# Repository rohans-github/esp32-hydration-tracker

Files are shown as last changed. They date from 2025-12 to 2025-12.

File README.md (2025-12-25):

# Hydration Tracker Using ESP32 Microcontroller
Created by Rohan

## Table of Contents
* [Report](#report)
* [Hardware Setup](#hardware-setup)
* [Code](#code)
* [Media](#media)
* [Citations](#citations)

## Report

### Quick Overview
The Hydration Tracker is a smart water bottle scale that helps users maintain proper hydration throughout the day. The device monitors water consumption in real-time, provides visual feedback on hydration status through the onboard LED and the website it hosts, and logs historical data for tracking progress over time.

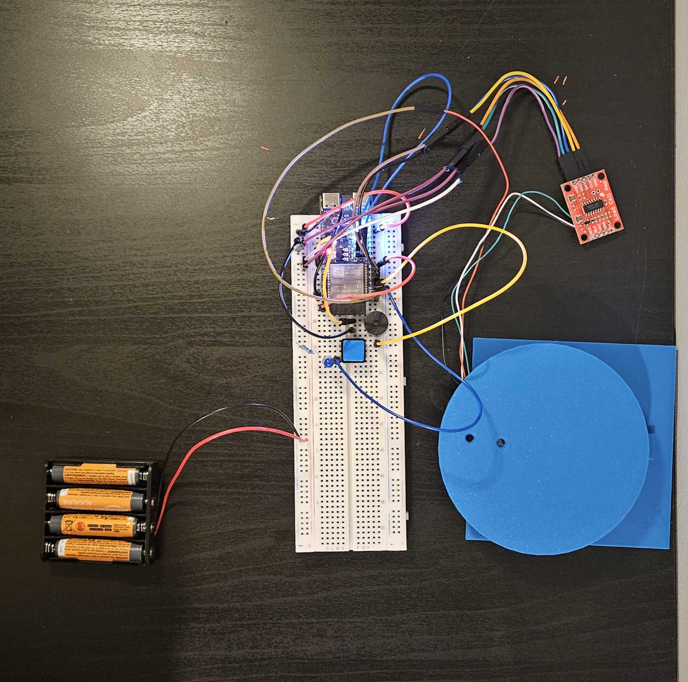
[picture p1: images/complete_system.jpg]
Complete System


### Component Overview
For the Hydration Tracker hardware, the following components are required:
* ESP32-C6-DevKitC-1 Microcontroller
  * The ESP32C6 contains the logic for the system and interacts with the other peripherals such as the buzzer to provide meaningful functionality.
  * Additionally, the onboard LED of the ESP32C6 acts as a visual indicator, showing white for when the system is waiting for user input for a session, red when the user is substantially behind their ideal hydration level during the session, yellow when the user is slightly behind their ideal hydration level during the session, green when the user is ahead of their ideal hydration level during the session, and purple when the user is at or surpasses their hydration goal for the session.
* HX711 Load Cell Amplifier
  * The load cell amplifier amplifies the tiny voltage offsets from the load cell into a more useable range of voltage that correlates to weight readings.
* Load Cell (5kg capacity)
  * The load cell measures strain along itself and outputs it as a change in voltage. The change in strain is measurable as a change in weight.
* Blue LED
  * The blue LED provides visual feedback to when the system is hosting the webpage. When the LED is on, the user is able to access the webpage.
* Button
  * The button tells the system to turn on WiFi capabilities so that the user can connect to it and view the webpage that the system hosts.
* Buzzer
  * The buzzer audibly notifies the user that they need to drink water to stay on track with their hydration goal for the session.
* Battery Pack
  * The battery pack is necessary to power on the system in a portable manner.
* Breadboard
  * The breadboard is necessary to easily connect all components together.
    
 ### Challenges Faced
 - Task running out of stack storage, which was solved by allocating more of the stack to the task
 - Getting NVS to work and store the session data
 - Separating the project into independent modules
 - External RGB LED had many flaws, had to switch to onboard LED
 - Had problems implementing sleep mode since the system would not register scale readings in sleep, making the system unresponsive and frustrating. To somewhat still save power, we implemented the web server button since WiFi was the peripheral that took up the most power.

### Similarities and Differences to Other Real-World Embedded Systems
The system is similar to other embedded systems in several areas, such as interactivity, responsive, and power. Some real-world embedded systems are interactive and have buttons, such as a car's AC system, that allow the user to use the system. Additionally, real-world embedded systems are responsive, meaning that clicking a button doesn't have a noticeable delay. The Hydration Monitor promotes user interactivity by hosting a web server where users can view and reset their hydration data. The web server button is connected to an interrupt, making it responsive as well. Real-world embedded systems should also be conservative in power as most of these systems run on an external battery. In this project, the system is able to disable web server and WiFi capabilities after it senses no clients for a set time, thus saving power. A major difference between this system and other real-world embedded systems is size. Most embedded systems implement a custom PCB to minimize the size of their system. This project on the other hand uses a breadboard and long wires that greatly increases its size, making it inconvenient to carry around and use.

### Improvements
Given more time and resources, some improvements could be
- Making UI/UX on website better
- Constructing scale with better materials and adding more structural support to stabilize scale when heavy objects are placed on it
- Implementing better logic to reliably detect hydration intake since some hydration intakes did not go through
- Soldering and reducing wire usage
- Creating custom PCB instead of ESP32 board

## Hardware Setup

### Wiring

| ESP32-C6 Pin | HX711 | Blue LED| Speaker | Push Button | Power |
| :---: | :---: | :-----: | :-----: | :---: | :---: |
| 5V | VCC | | | | + | 
| GND | GND | Cathode | - | GND | - |
| GPIO 4 | |  Anode  | | | |
| GPIO 5 | | | | Signal | |
| GPIO 6 | DAT | | | | |
| GPIO 7 | CLK | | | | |
| GPIO 21 | | | + | | |

**Load Cell Wiring:**
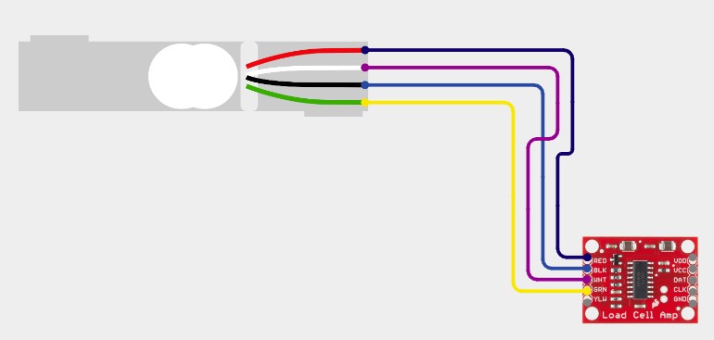
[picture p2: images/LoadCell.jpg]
LoadCell
### 

- E+ → RED
- E- → BLK
- A- → WHT
- A+ → GRN

**Circuit Diagram:**
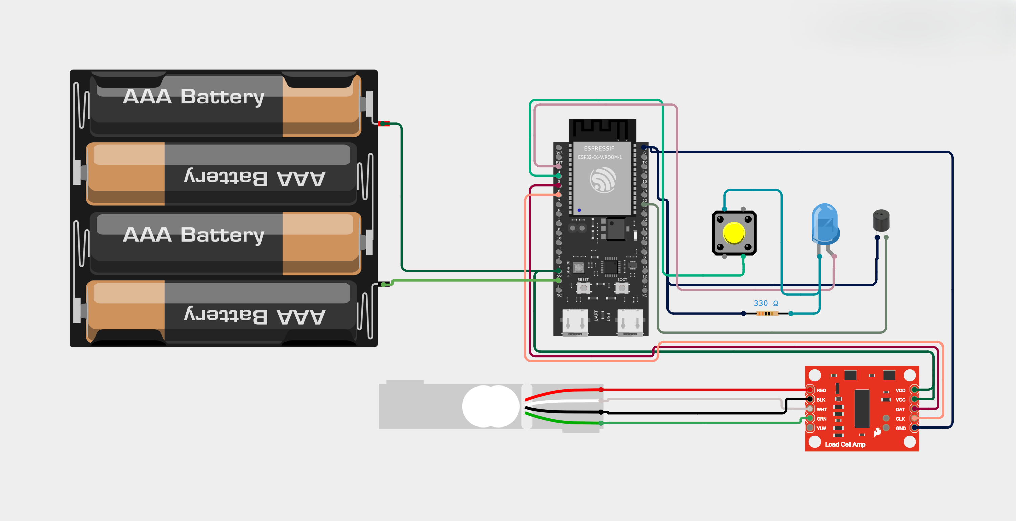
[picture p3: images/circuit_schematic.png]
Circuit Diagram
### 

### Assembly Notes

The load cell should be mounted in a stable configuration to accurately measure the weight of the water bottle. We recommend:
1. Securing the load cell to a flat, rigid base
2. Creating a platform on top of the load cell for the water bottle to rest on
3. Ensuring the load cell is calibrated before first use (calibration value in `config.h`)

The blue LED serves as a web server status indicator:
- **Solid Blue**: Web server enabled
- **Off**: Web server disabled

The onboard LED provides hydration status feedback:
- **Green**: On track with hydration goals
- **Yellow**: Falling behind, should drink soon  
- **Red**: Critical, need to drink immediately

## Code

### Module Architecture

The codebase is organized into modular components, each handling a specific aspect of the system:

#### **config.h**
Central configuration file containing:
- Pin definitions for all hardware components
- Calibration values for the load cell
- LED state definitions for different hydration levels
- Storage configuration for historical data

#### **scale.cpp / scale.h**
Handles the HX711 load cell interface:
- Initializes the HX711 with calibration values
- Reads weight measurements with stability checking
- Calculates delta (change in weight) to detect water consumption
- Implements filtering to reduce noise

#### **hydration.cpp / hydration.h**
Manages hydration tracking logic:
- Tracks total water consumed vs. session goal
- Calculates ideal consumption rate over time
- Determines hydration state (HYDRATED, NEEDS_WATER, CRITICAL)
- Updates status based on consumption pattern
- Provides reset functionality for new session periods

#### **status_led.cpp / status_led.h**
Controls the onboard LED feedback:
- Initializes the ESP32-C6 onboard LED
- Maps hydration states to LED patterns:
  - **Green**: On track with hydration
  - **Yellow**: Falling behind, should drink soon
  - **Red**: Critical, need to drink immediately
  - **Purple**: Met/exceeded session goal
- Provides visual status at a glance

#### **speaker.cpp / speaker.h**
Manages audio alerts:
- Generates tone alerts using PWM
- Plays periodic reminders when hydration is critical
- Implements alert timing to avoid annoyance
- Can be silenced when hydration improves

#### **storage.cpp / storage.h**
Handles non-volatile memory operations:
- Stores up to 7 sessions using NVS (Non-Volatile Storage)
- Each session saves daily consumption data with session lengths
- Provides data retrieval for web interface

#### **web.cpp / web.h**
Implements WiFi access point and web server:
- Creates a WiFi hotspot (SSID: "Hydration Tracker")
- Serves HTML page with real-time hydration data
- Provides AJAX endpoints for live updates
- Displays historical consumption in table format
- Allows users to reset tracking data
- Can be toggled on/off via push button

#### **4180.ino**
Main program file that:
- Initializes all hardware modules
- Creates FreeRTOS tasks for concurrent operation:
  - `taskReadScale`: Monitors scale for weight changes (every 100ms)
  - `taskUpdateStatusLED`: Updates onboard LED based on hydration state (every 2s)
  - `taskAlertUser`: Triggers speaker alerts when needed (every 1s)
  - `taskHTMLPage`: Handles web server requests (every 10ms)
  - `taskWiFiControl`: Manages WiFi button and blue LED status
- Manages end-of-day data logging and resets

## Media

### System Overview
Complete System
*Fully assembled hydration tracker with ESP32-C6, load cell, blue WiFi LED, push button, and speaker*

### Hardware Components
Hardware Setup
*Wiring diagram showing connections between ESP32-C6, HX711, and peripherals*

### LED Status Indicators
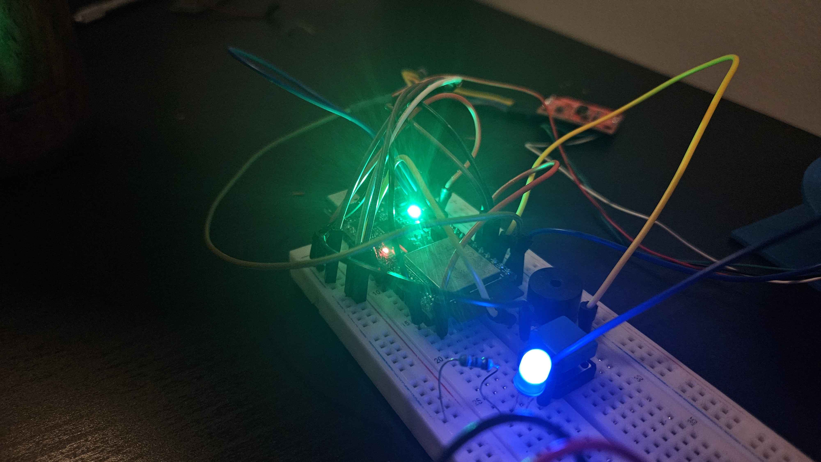
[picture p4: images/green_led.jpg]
Onboard LED - Hydrated

*Green onboard LED indicating good hydration status*

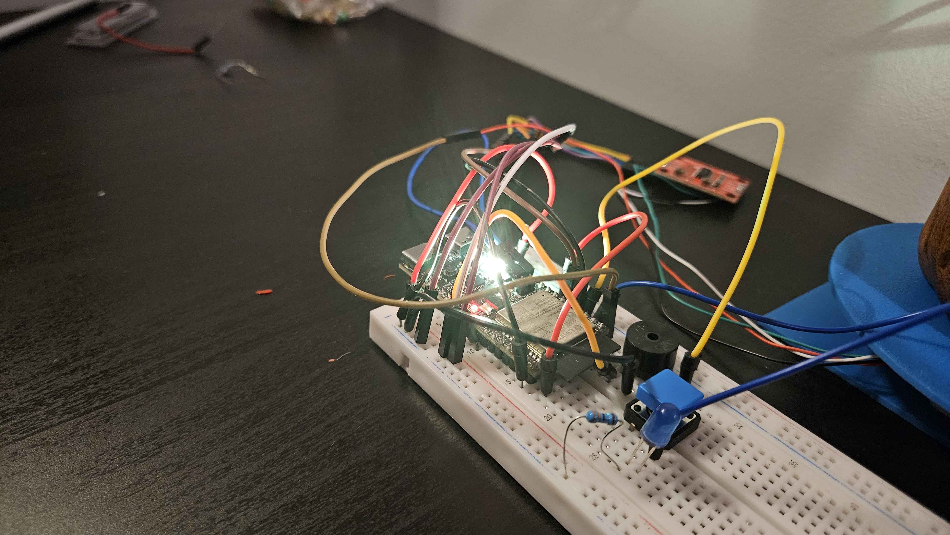
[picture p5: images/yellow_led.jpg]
Onboard LED - Needs Water

*Yellow onboard LED indicating user should drink soon*

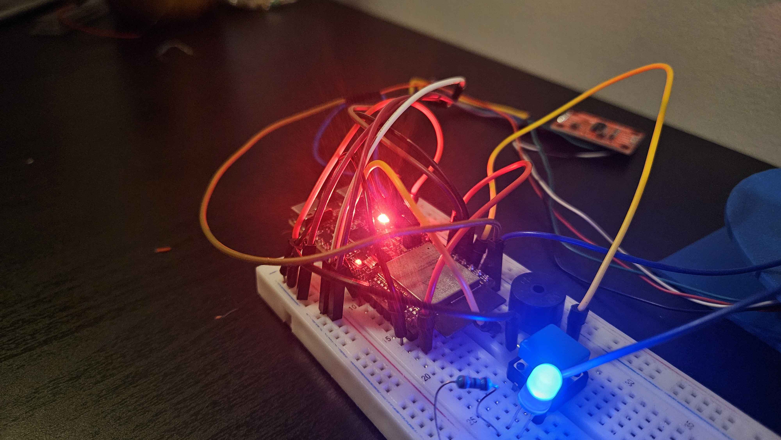
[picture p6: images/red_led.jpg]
Onboard LED - Critical

*Red onboard LED indicating critical hydration status*

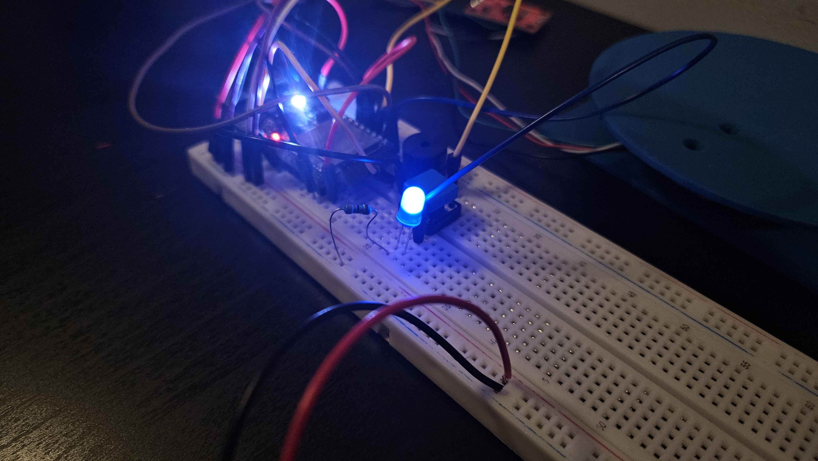
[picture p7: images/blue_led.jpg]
Blue WiFi LED

*Blue LED indicating WiFi is active and web interface is accessible*

### Web Interface
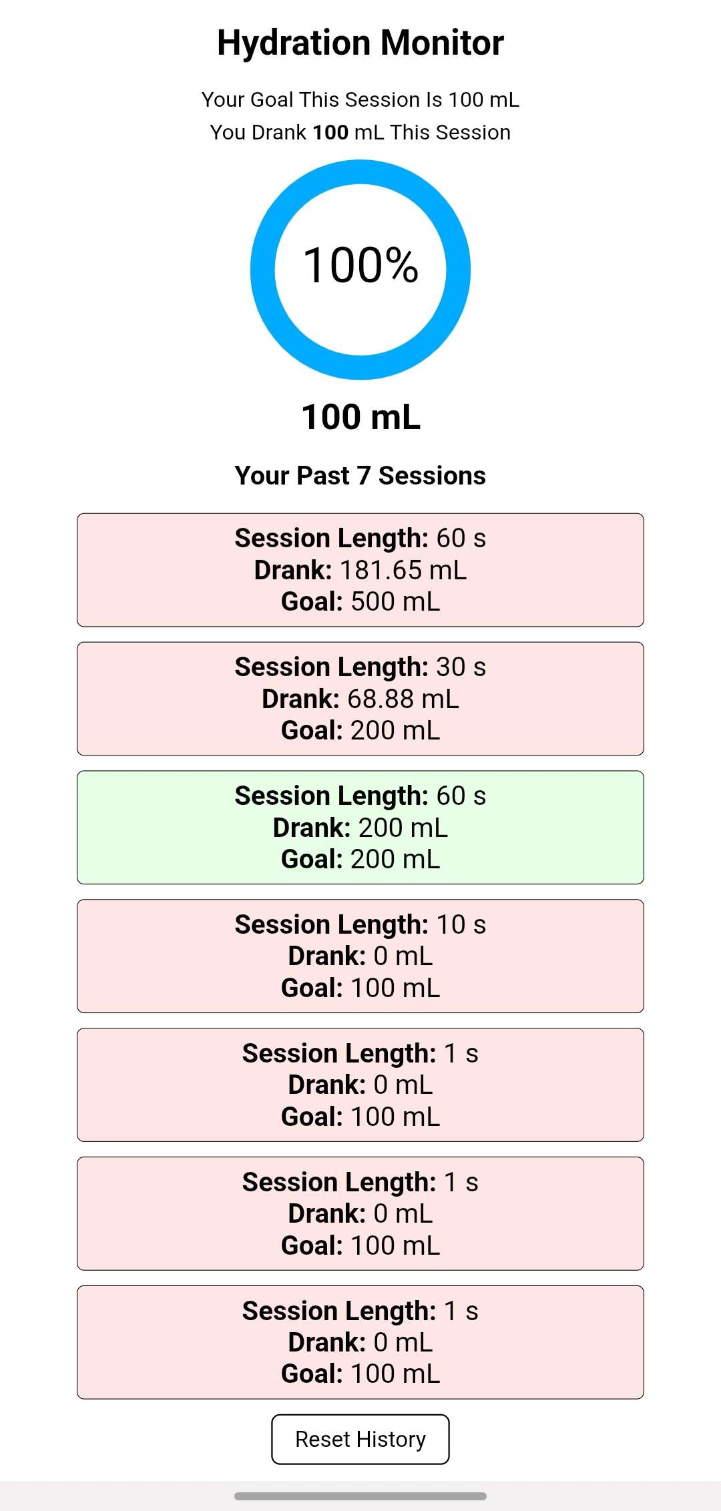
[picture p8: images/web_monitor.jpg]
Web Dashboard

*Web interface showing current hydration level and 7-day history*

### Device in Use
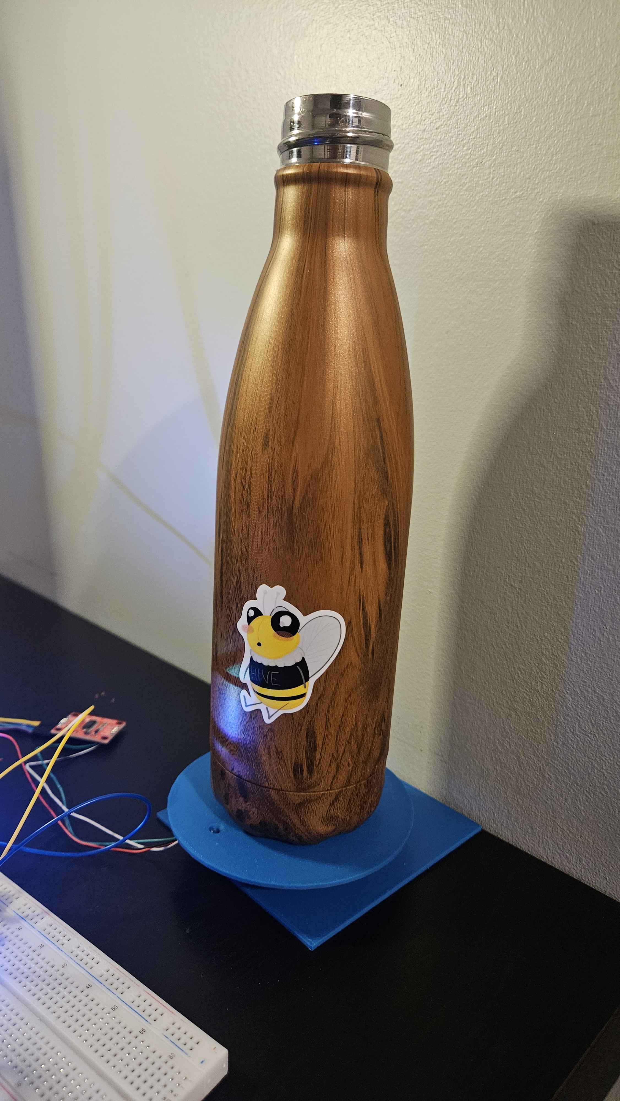
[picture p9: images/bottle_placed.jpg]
Water Bottle on Scale

*Water bottle positioned on the load cell platform*

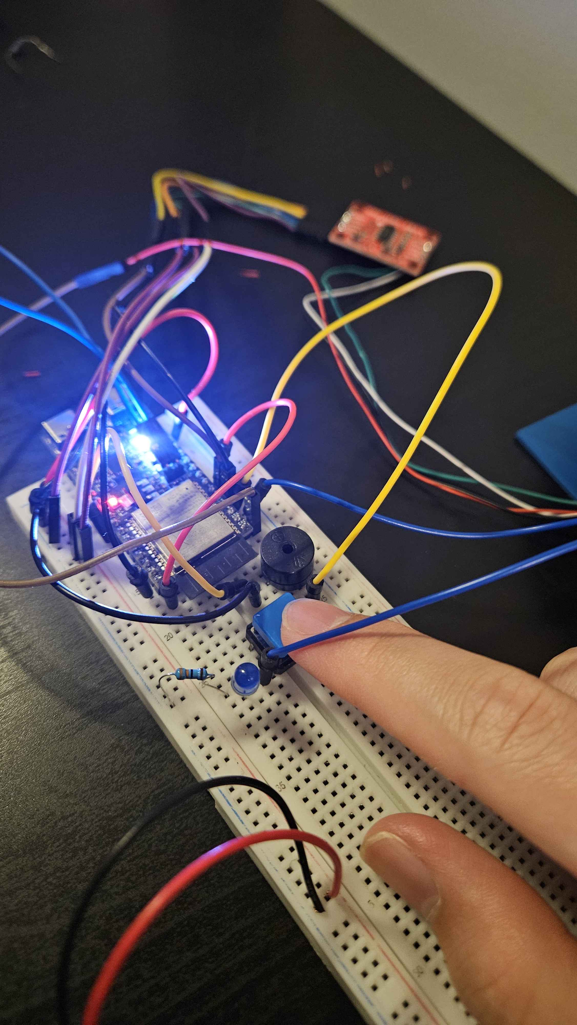
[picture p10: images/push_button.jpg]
Push Button Control

*Push button for toggling WiFi connectivity*

## Citations
- Arduino.h: https://github.com/espressif/arduino-esp32
- Wifi.h: https://github.com/espressif/arduino-esp32/tree/master/libraries/WiFi
- HX711.h: https://github.com/RobTillaart/HX711
- Adafruit_NeoPixel.h: https://github.com/adafruit/Adafruit_NeoPixel
- nvs_flash.h: https://github.com/espressif/esp-idf/blob/master/components/nvs_flash/include/nvs_flash.h
- nvs.h: https://github.com/espressif/esp-idf-nvs-partition-gen
- FreeRTOS (built-in): https://docs.espressif.com/projects/esp-idf/en/stable/esp32/api-reference/system/freertos.html

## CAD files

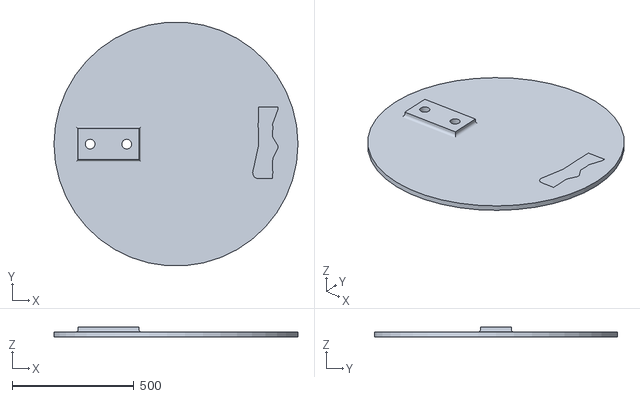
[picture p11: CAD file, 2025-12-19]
mechanical/Load_cell_top_plate.stl
1000.0 x 997.2 x 40.0

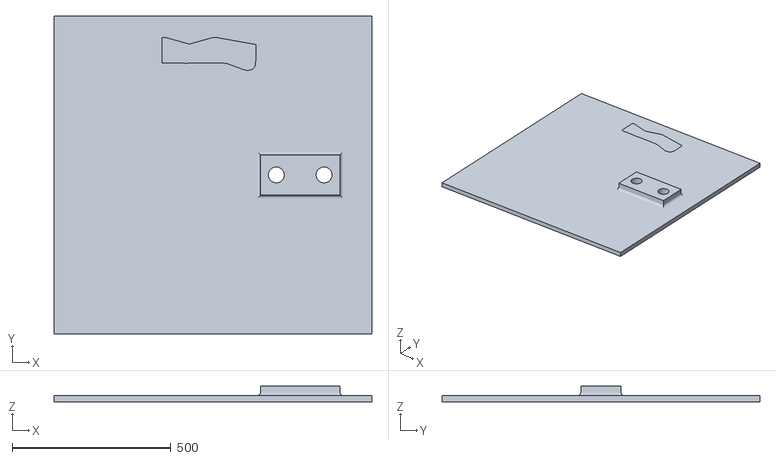
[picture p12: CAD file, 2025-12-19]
mechanical/Load_cell_bottom_plate.stl
1000.0 x 1000.0 x 50.0

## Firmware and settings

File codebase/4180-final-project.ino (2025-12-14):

#include <Arduino.h>
#include "speaker.h"
#include "hydration.h"
#include "status_led.h"
#include "scale.h"
#include "storage.h"
#include "web.h"
#include "state.h"

/*
Updates onboard LED to show various conditions
*/
void taskUpdateStatusLED(void *pv) {
  while(1) {
    //until user enters required input for the session, make LED turn white
    while (get_state() == STATE_WAITING_USER_INPUT) {
      status_led_show_waiting();
      vTaskDelay(pdMS_TO_TICKS(100));
    }
    //updates LED based on hydration state
    status_led_update(get_hydration_state());
    vTaskDelay(pdMS_TO_TICKS(100));
  }
}

/*
Speaker that audibly alerts the user when the LED is red and the user needs to drink water
*/
void taskAlertUser(void *pv) {
  while(1) {
    //while waiting for user input don't use the speaker
    while (get_state() == STATE_WAITING_USER_INPUT) {
      speaker_stop();
      vTaskDelay(pdMS_TO_TICKS(100));
    }
    //if hydration state is critical then sound speaker
    if (get_hydration_state() == CRITICAL) {
      speaker_alert();
    }
    vTaskDelay(pdMS_TO_TICKS(1000));
  }
}

/*
Generates HTML page allowing user to view hydration data and interact with system wirelessly through Wifi
*/
void taskHTMLPage(void *pv) {
  while(1) {   
    //if user presses web page button, turn on web page
    if (get_web_request()) { 
      web_enable();
      unsigned long client_connect_time = millis();
      
      while(1) {
        bool no_client = false;
        //if waiting for user input then don't read from hydration.cpp
        if (get_state() == STATE_RUNNING) {
          set_goal_grams(get_goal_grams());
          set_total_grams(get_total_grams());
        }
        
        //if true, then there is a client connected
        if (webserver_handle_client()) {
          client_connect_time = millis();
        }
        //keep web page on until CLIENT_TIMEOUT_SECS seconds pass with no client
        if (millis() - client_connect_time > CLIENT_TIMEOUT_SECS * 1000) {
          break;
        }
        vTaskDelay(5);
      }
      //disable the website
      set_web_request(false);
      web_disable();
    }
    vTaskDelay(10);
  }
}

/*
Detects scale changes and stores meaningful changes in non-volatile memory
*/
void taskReadScale(void *pv) {
  float prev_weight = 0;  //stores last weight detected
  Entry html_page_entries[MAX_ENTRIES]; //holds data from storage to be populated to web
  storage_load_entries(html_page_entries);  //load entries from non-volatile memory to html_page_entries
  set_history(html_page_entries); //sends data to website
  while (1) {
    //while waiting for user input, do not use the scale
    while (get_state() == STATE_WAITING_USER_INPUT) {
      vTaskDelay(pdMS_TO_TICKS(100));
    }
    //read the weight on the scale
    float current_weight = scale_read_weight();
    
    // If there is something on the scale, weight decreased, and difference is meaningful
    if (current_weight > 30.0 && current_weight < prev_weight && prev_weight - current_weight > 30.0) {
      record_grams_drank(prev_weight - current_weight);  //record the difference in weight between previous reading and current reading
    }

    if (current_weight > 30.0)
      prev_weight = current_weight; //save current weight as previous weight to detect drops in weight

    update_hydration_status();

    //if the pacer is 0, then that means the session ended
    if (get_pacer() == 0) {
      //store the sessions total water intake, the goal, and the session length in memory
      storage_add_entry(get_total_grams(), get_goal_grams(), get_time_length());

      //load past sessions into web page
      storage_load_entries(html_page_entries);
      set_history(html_page_entries);
      
      //refresh when session ends so user input overlay appear automatically
      set_refresh_flag(true);
      //user needs to input new information for new session after this session ends
      set_state(STATE_WAITING_USER_INPUT);
    }
    vTaskDelay(pdMS_TO_TICKS(100));
  }
}

void setup() {
  //init
  Serial.begin(115200);
  scale_init();
  status_led_init();
  web_init();
  speaker_init();
  storage_init();
  
  //task creation
  xTaskCreate(taskUpdateStatusLED, "taskUpdateStatusLED", 2048, NULL, 3, NULL);
  xTaskCreate(taskAlertUser, "taskAlertUser", 2048, NULL, 3, NULL);
  xTaskCreate(taskReadScale, "taskReadScale", 4096, NULL, 1, NULL);
  xTaskCreate(taskHTMLPage, "taskHTMLPage", 4096, NULL, 2, NULL);
}

void loop() {
}

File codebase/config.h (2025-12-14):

#ifndef CONFIG_H
#define CONFIG_H

#include <Arduino.h>

//DEBUG ---------
#define DEBUG 0

//SCALE -----------------------------------------------------------
#define SCALE_DATA_PIN 6
#define SCALE_CLK_PIN 7
#define SCALE_CALIBRATION_VAL -256.602600

//HYDRATION -----------------------------------------------------------
enum HydrationState {
    COMPLETED,
    HYDRATED,
    NEEDS_WATER,
    CRITICAL
};

//SPEAKER -----------------------------------------------------------
#define SPEAKER_PIN 21
#define ALERT_FREQUENCY 1000  // Hz
#define ALERT_DURATION 500    // ms
#define ALERT_INTERVAL 30000  // 30 seconds between alerts

enum SpeakerState {
  SPEAKER_IDLE,
  SPEAKER_ALERTING
};

//STATUS LED -----------------------------------------------------------
#define LED_PIN 8
#define NUM_LEDS 1
#define LED_PWM_FREQ 5000
#define LED_PWM_RESOLUTION 8  // 8-bit resolution (0-255)

// LED color definitions (RGB values)
struct LEDColor {
  uint8_t red;
  uint8_t green;
  uint8_t blue;
};

// Predefined colors for hydration states
#define COLOR_GOOD      {0, 255, 0}      // Green - well hydrated
#define COLOR_OK        {255, 255, 0}    // Yellow - acceptable
#define COLOR_CRITICAL    {255, 0, 0}      // Red - drink water
#define COLOR_COMPLETED    {128, 0, 128}      // Purple - goal met
#define COLOR_OFF       {0, 0, 0}        // Off

//STORAGE -----------------------------------------------------------
// Number of sessions to store
#define MAX_ENTRIES 7

// Structure to hold a single session's hydration data
struct Entry {
  uint32_t duration;        // session length in seconds
  float grams_drank;      // total grams of water consumed during session
  float goal;          // goal set for session
};

//WEB -----------------------------------------------------------
#define BTN_PIN 5
#define WEB_STATUS_PIN 4
#define CLIENT_TIMEOUT_SECS 30

//STATE -----------------------------------------------------------
typedef enum {
    STATE_WAITING_USER_INPUT,
    STATE_RUNNING
} SystemState;

#endif

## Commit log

2025-12-14 Revise README for Hydration Tracker project
    Updated README to provide detailed project overview, hardware setup, and code architecture for the Hydration Tracker using ESP32.
2025-12-19 Add title to README for STL files
